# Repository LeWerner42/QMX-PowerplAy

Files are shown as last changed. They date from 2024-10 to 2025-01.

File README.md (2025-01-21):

# USB-C PD adapter for QMX + 50W PA

The QMX-PowerplAy is designed to power the [QRP Labs QMX](https://qrp-labs.com/qmx.html) as well as the [50W PA](https://qrp-labs.com/50wpa.html) off a USB PD Powerbank.
Designed for ultimate portability for SOTA / POTA activations, the board can negotiate `15V` or `20V` with `3A` or `5A` for the PA.
A `12V, 5A` switching regulator powers the QMX. Power Negotiation can be selected with simple Jumpers.

## Hardware
### Schematic
The main component is the [AP33771C](https://www.mouser.ch/ProductDetail/Diodes-Incorporated/AP33771CFBZ-13-FA01?qs=2wMNvWM5ZX7JpCFGcPz6nw%3D%3D) which takes care of USB PD negotiations.
Output Voltage and Current can be set through Jumpers `JP1` and `JP2`.
[The Barrel Jack](https://www.mouser.ch/ProductDetail/Wurth-Elektronik/694106301002?qs=a9WhcLg8qCwOEkcI62k5mA%3D%3D) J2 (5.5mm) directly connects to the negotiated power from USB.
J3 (5.5mm) is connected to the stepped-down 12V for supplying the QMX
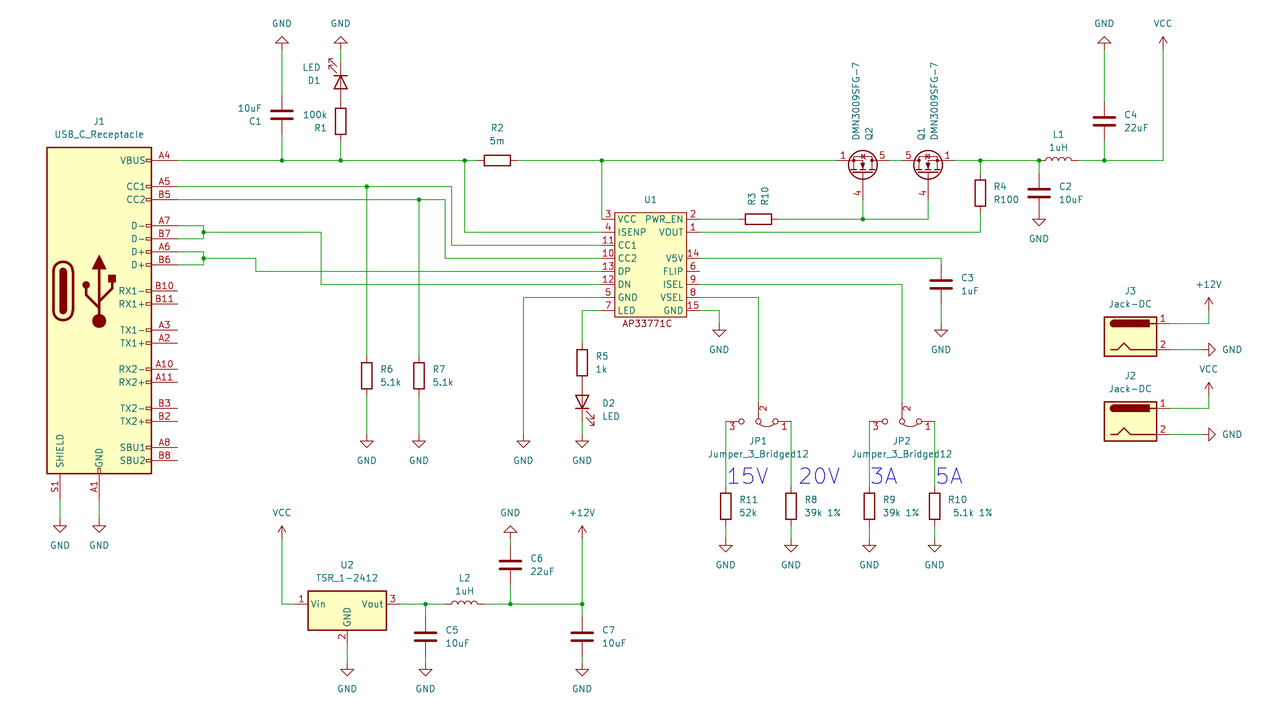
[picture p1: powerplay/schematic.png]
schematic Board Schematic


### Manufacturing
PCBs can be ordered with the gerbers in [fabrication](./powerplay/fabrication).  
The [Component BOM](https://lewerner42.github.io/QMX-PowerplAy/powerplay/bom/ibom.html) [`powerplay/bom/ibom.html`] lists all neccessary components for soldering.
Be aware of Capacitor Voltage ratings (>= 20V) for capacitors connected to USB power.
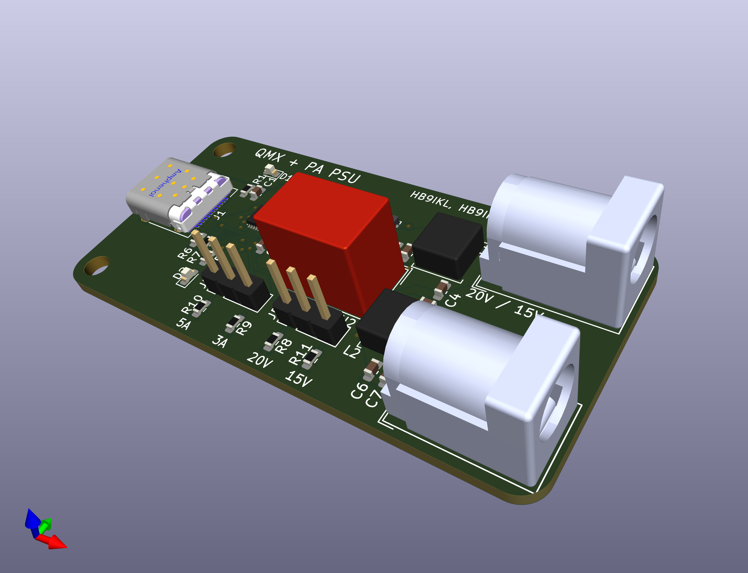
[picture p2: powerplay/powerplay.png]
rendering Board Render


## Case
The case is entirely 3D printable and files can be accessed in the [Case](./Case) folder.
The `12V` output is labled `QMX` and the USB power (`15V` or `20V`) is labled `PA`.

## Usage
No Substantial Load should be attached to the barrel jacks when powering up.
The QMX and PA can be connected during power-up.
Successfull power negotiation is indicated by LED 2 (`D2`) breathing.
LED 1 (`D1`) indicates if power is present at all.
In case of failiure to negotiate the requested power level either the highest possible negotiated power is present (e.g. `20V`, `3A` even though `100W` were requested) or only `5V` are present on the PA port.
The step-down (`12V` output) only works if the USB voltage is `> 12V`.
Jumpers `JP1` and `JP2` can be used to change the negotiated power according to the capabilities of the used supply.
The Power select Jumpers are NOT hot-swappable. Change them only when the device is unconnected.

# Authors
This board has been developed specifically for SOTA and POTA purposes by Pol (HB9IKL) and Lennart (HB9IKK).

# License


This work is licensed under Creative Commons Attribution-ShareAlike 3.0 Unported License. 
(http://creativecommons.org/licenses/by-sa/3.0/)

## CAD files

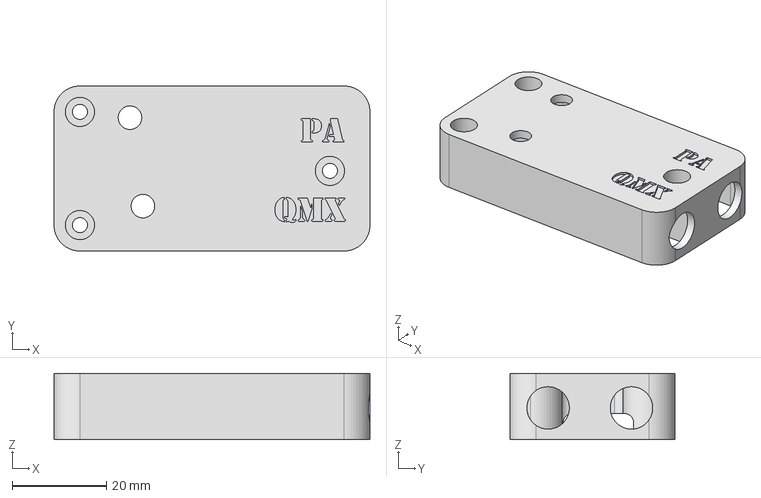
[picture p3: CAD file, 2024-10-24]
Case/Case_Cap.stp
67.0 x 35.0 x 14.0 mm

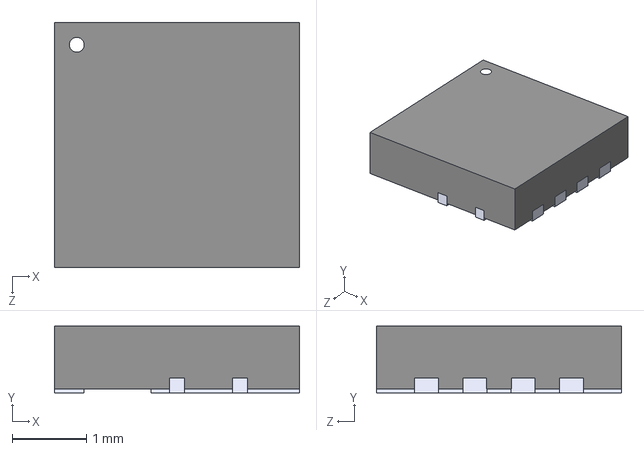
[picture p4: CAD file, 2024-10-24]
powerplay/3dModels/DMN3009SFG-7.stp
3.30 x 0.9 x 3.30 mm

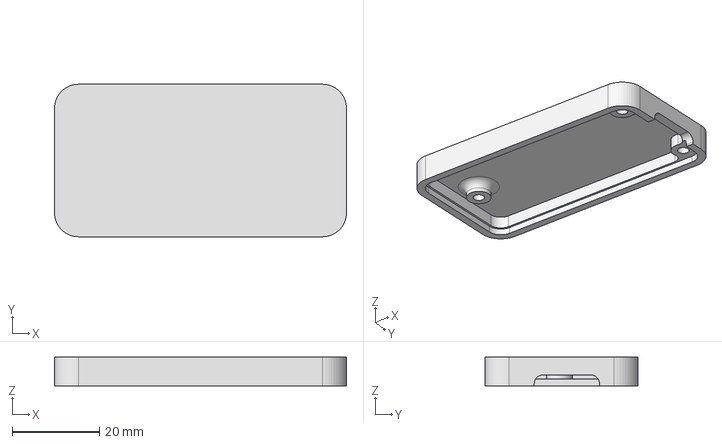
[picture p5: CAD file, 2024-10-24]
Case/case_base.stp
67.0 x 35.0 x 6.60 mm

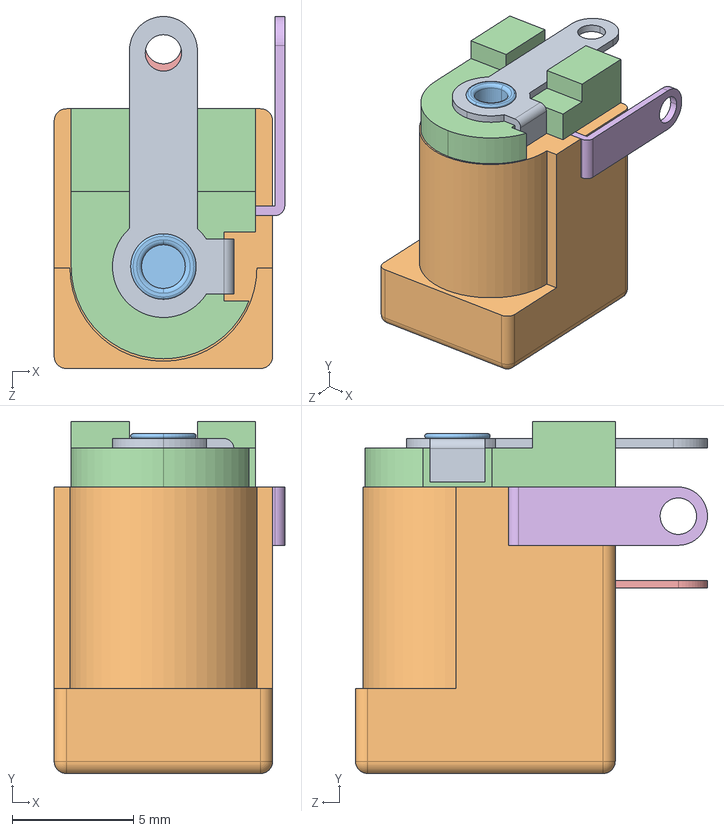
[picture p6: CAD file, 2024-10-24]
powerplay/3dModels/694106301002.stp
9.50 x 14.5 x 14.5 mm

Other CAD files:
Case/Case_Cap.ipt
Case/OldVersions/Case_Cap.0005.ipt
Case/OldVersions/case_assambly.0003.iam
Case/OldVersions/case_base.0003.ipt
Case/case_assambly.iam
Case/case_base.ipt

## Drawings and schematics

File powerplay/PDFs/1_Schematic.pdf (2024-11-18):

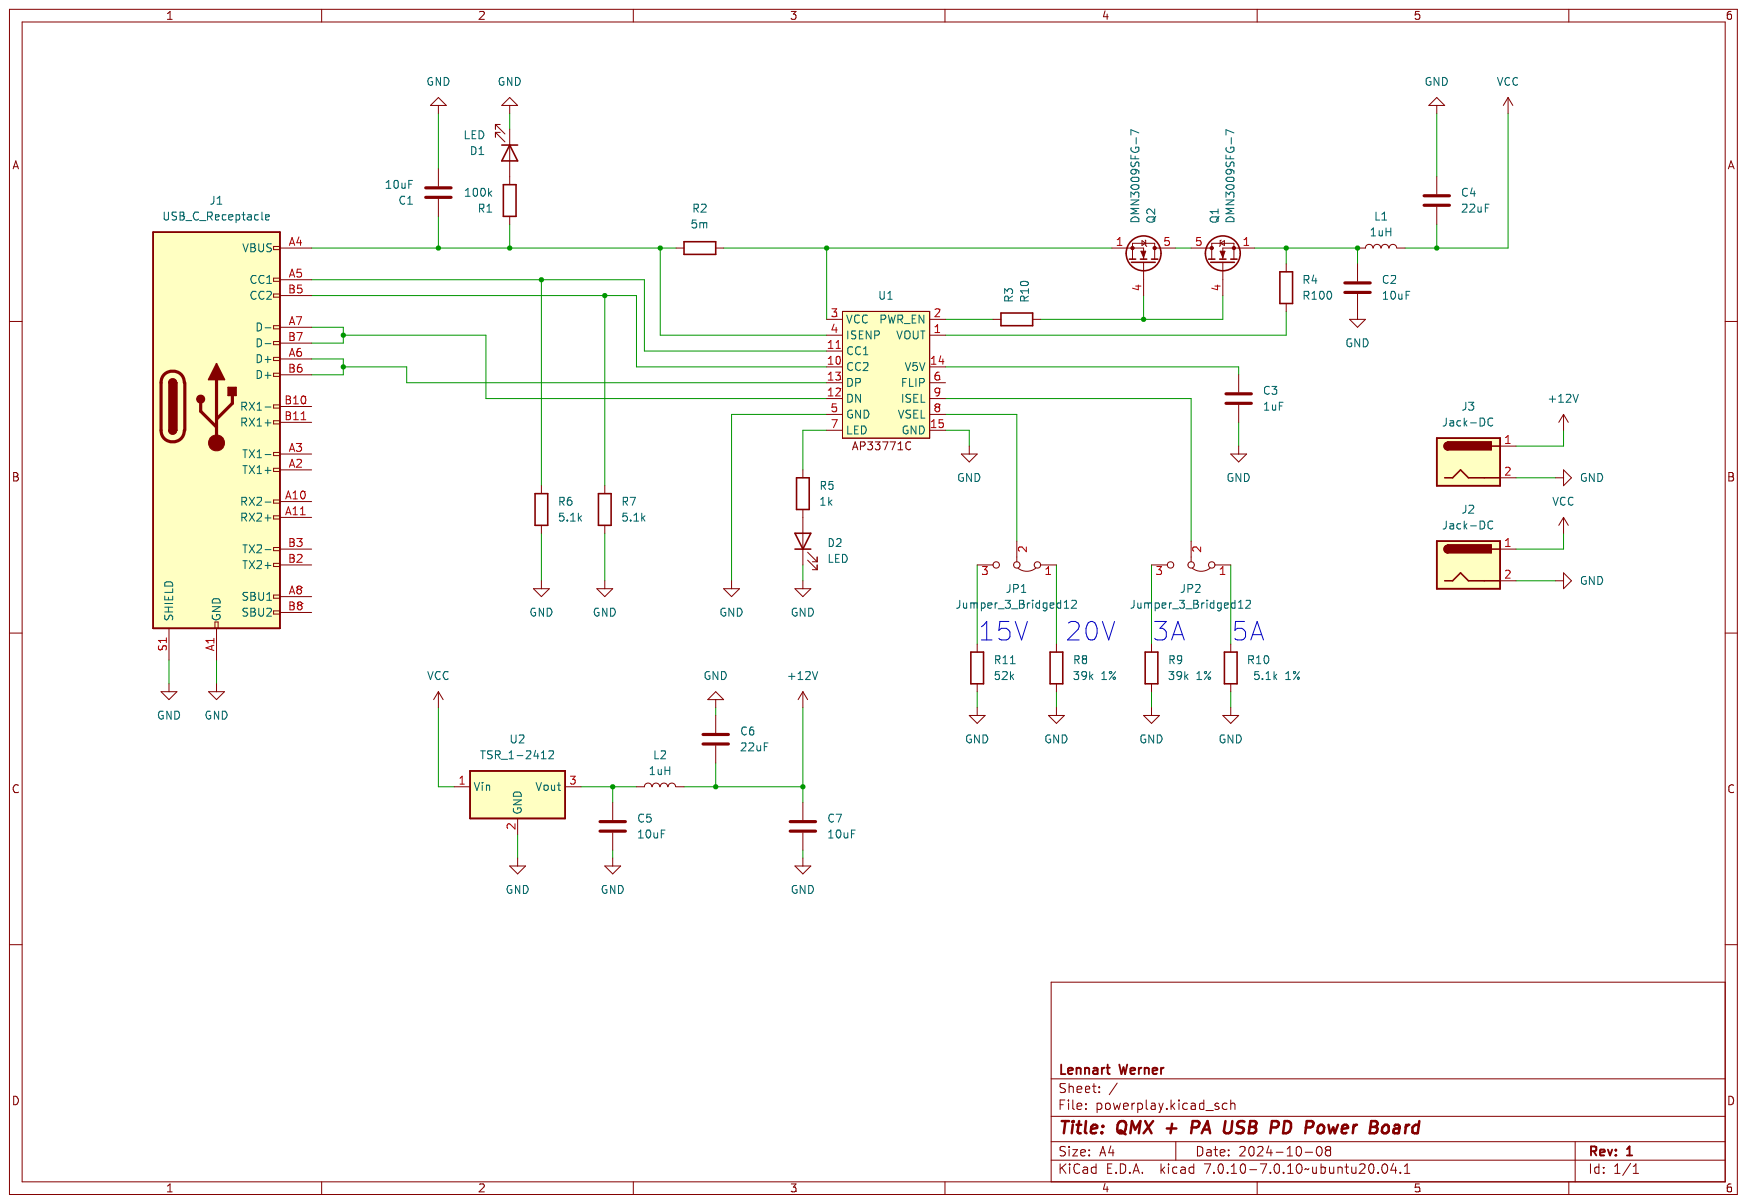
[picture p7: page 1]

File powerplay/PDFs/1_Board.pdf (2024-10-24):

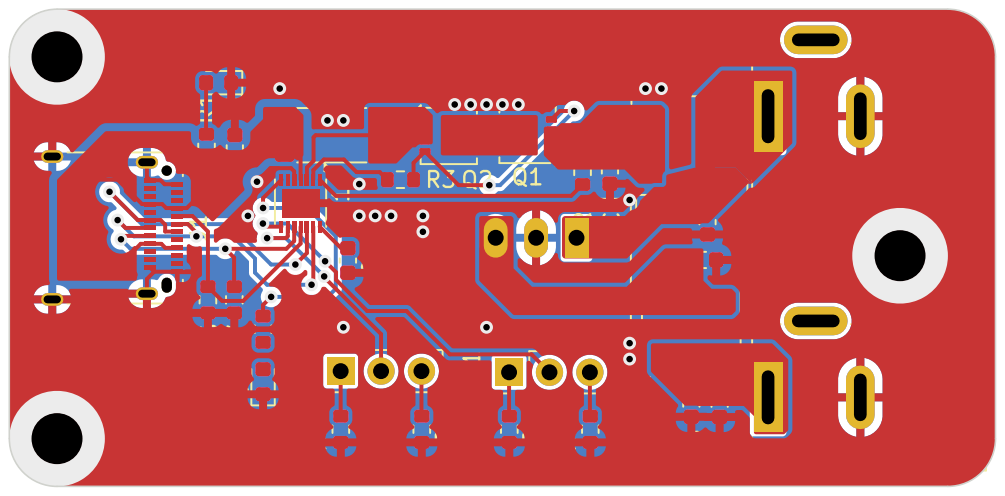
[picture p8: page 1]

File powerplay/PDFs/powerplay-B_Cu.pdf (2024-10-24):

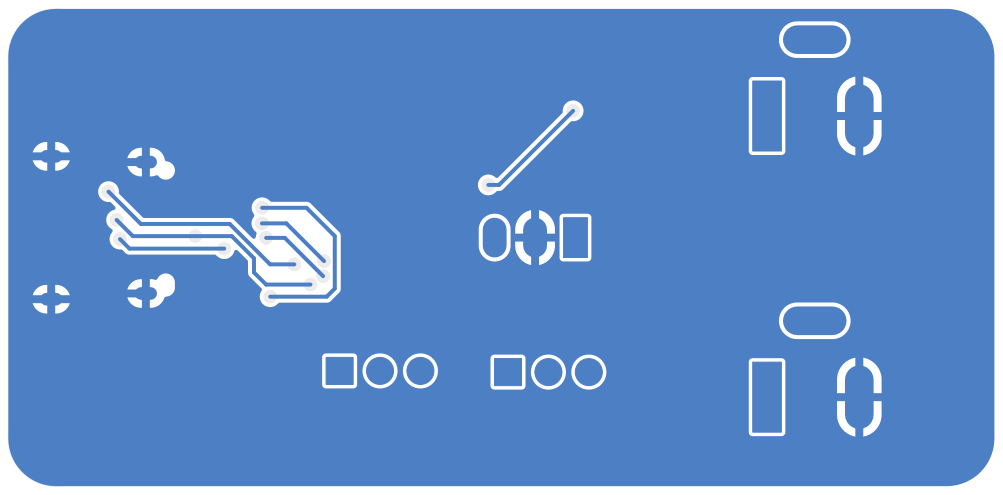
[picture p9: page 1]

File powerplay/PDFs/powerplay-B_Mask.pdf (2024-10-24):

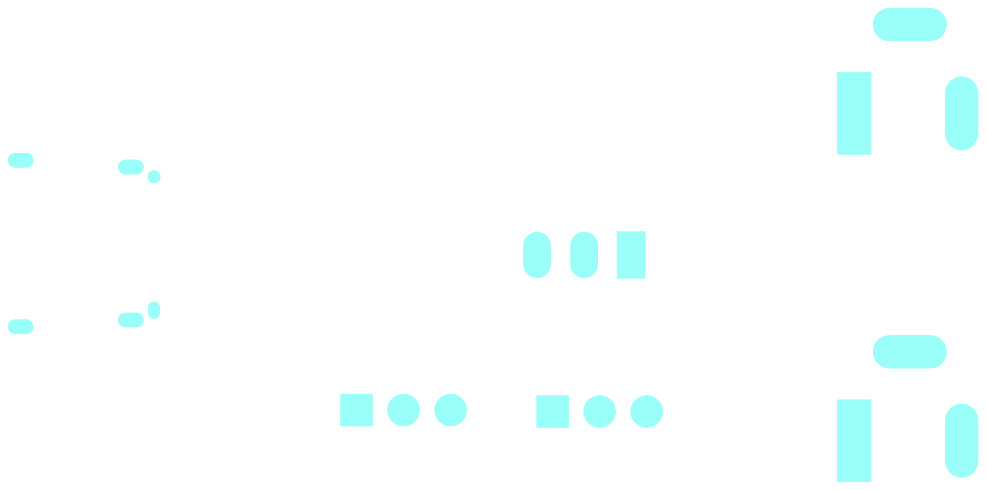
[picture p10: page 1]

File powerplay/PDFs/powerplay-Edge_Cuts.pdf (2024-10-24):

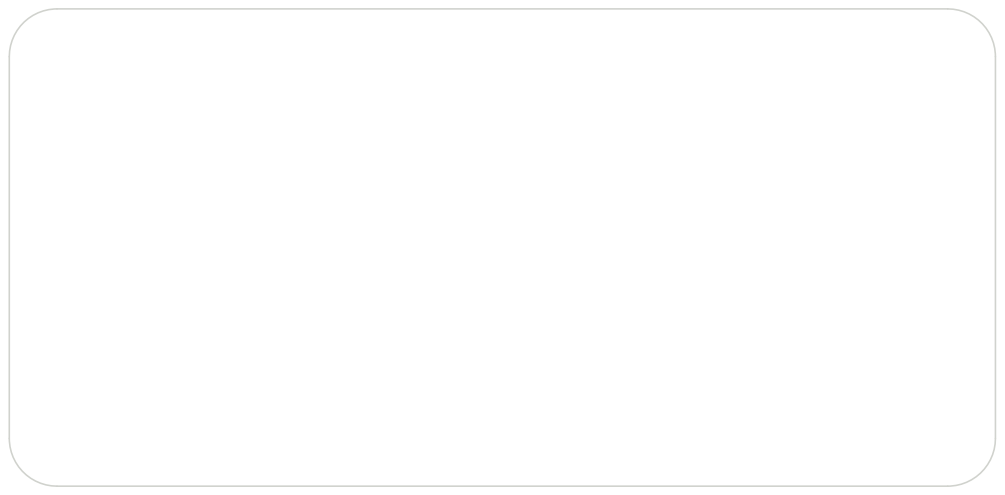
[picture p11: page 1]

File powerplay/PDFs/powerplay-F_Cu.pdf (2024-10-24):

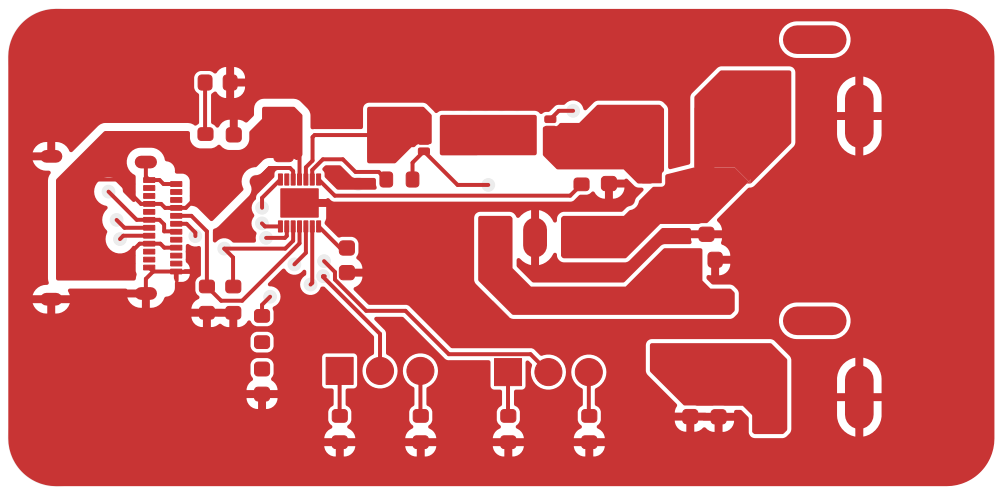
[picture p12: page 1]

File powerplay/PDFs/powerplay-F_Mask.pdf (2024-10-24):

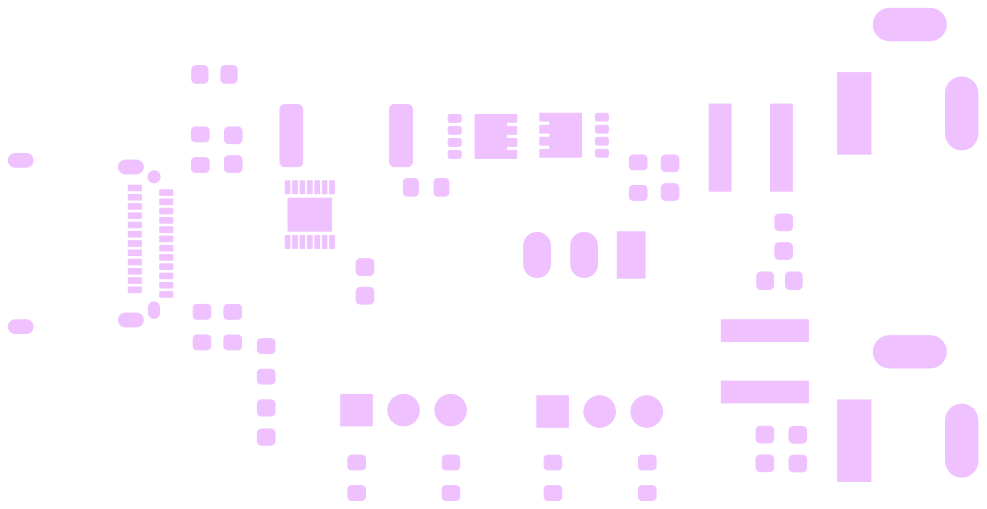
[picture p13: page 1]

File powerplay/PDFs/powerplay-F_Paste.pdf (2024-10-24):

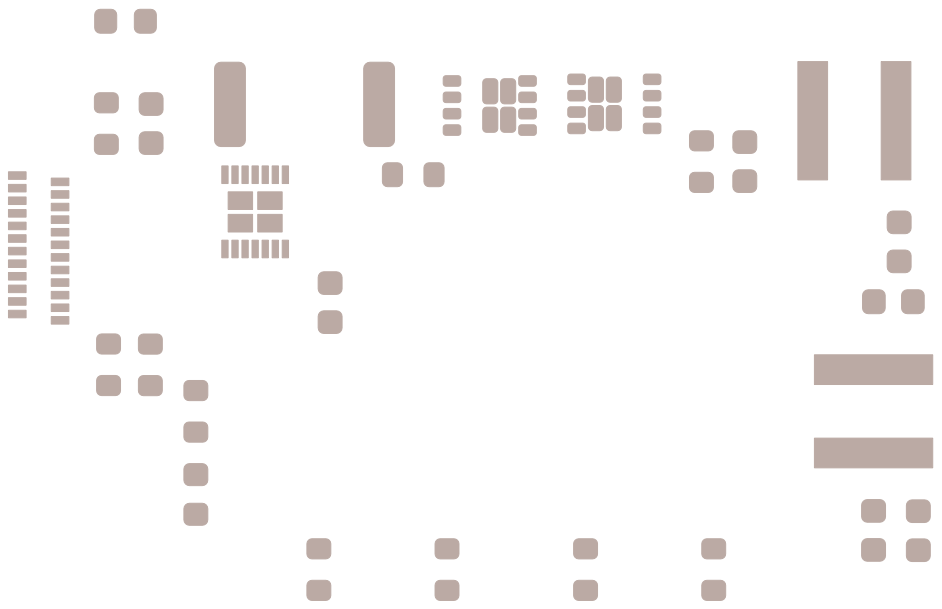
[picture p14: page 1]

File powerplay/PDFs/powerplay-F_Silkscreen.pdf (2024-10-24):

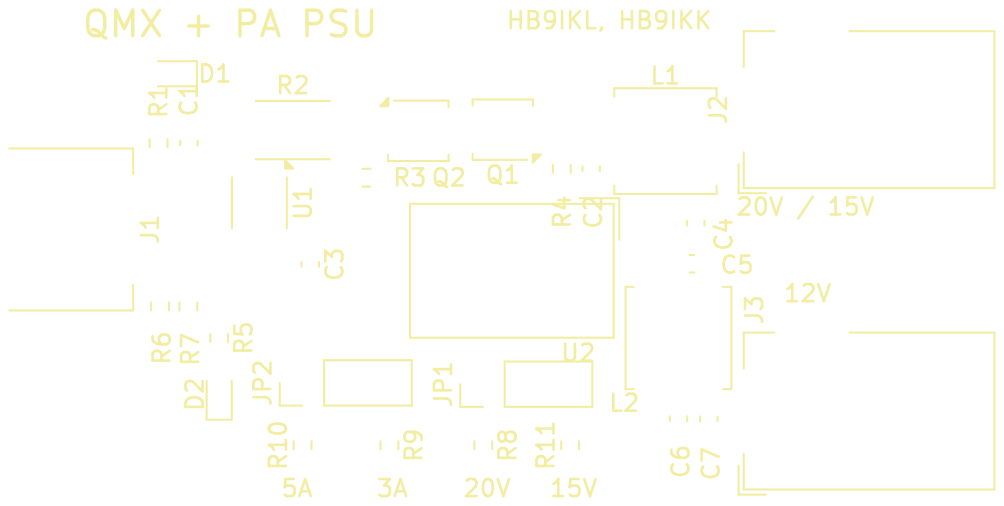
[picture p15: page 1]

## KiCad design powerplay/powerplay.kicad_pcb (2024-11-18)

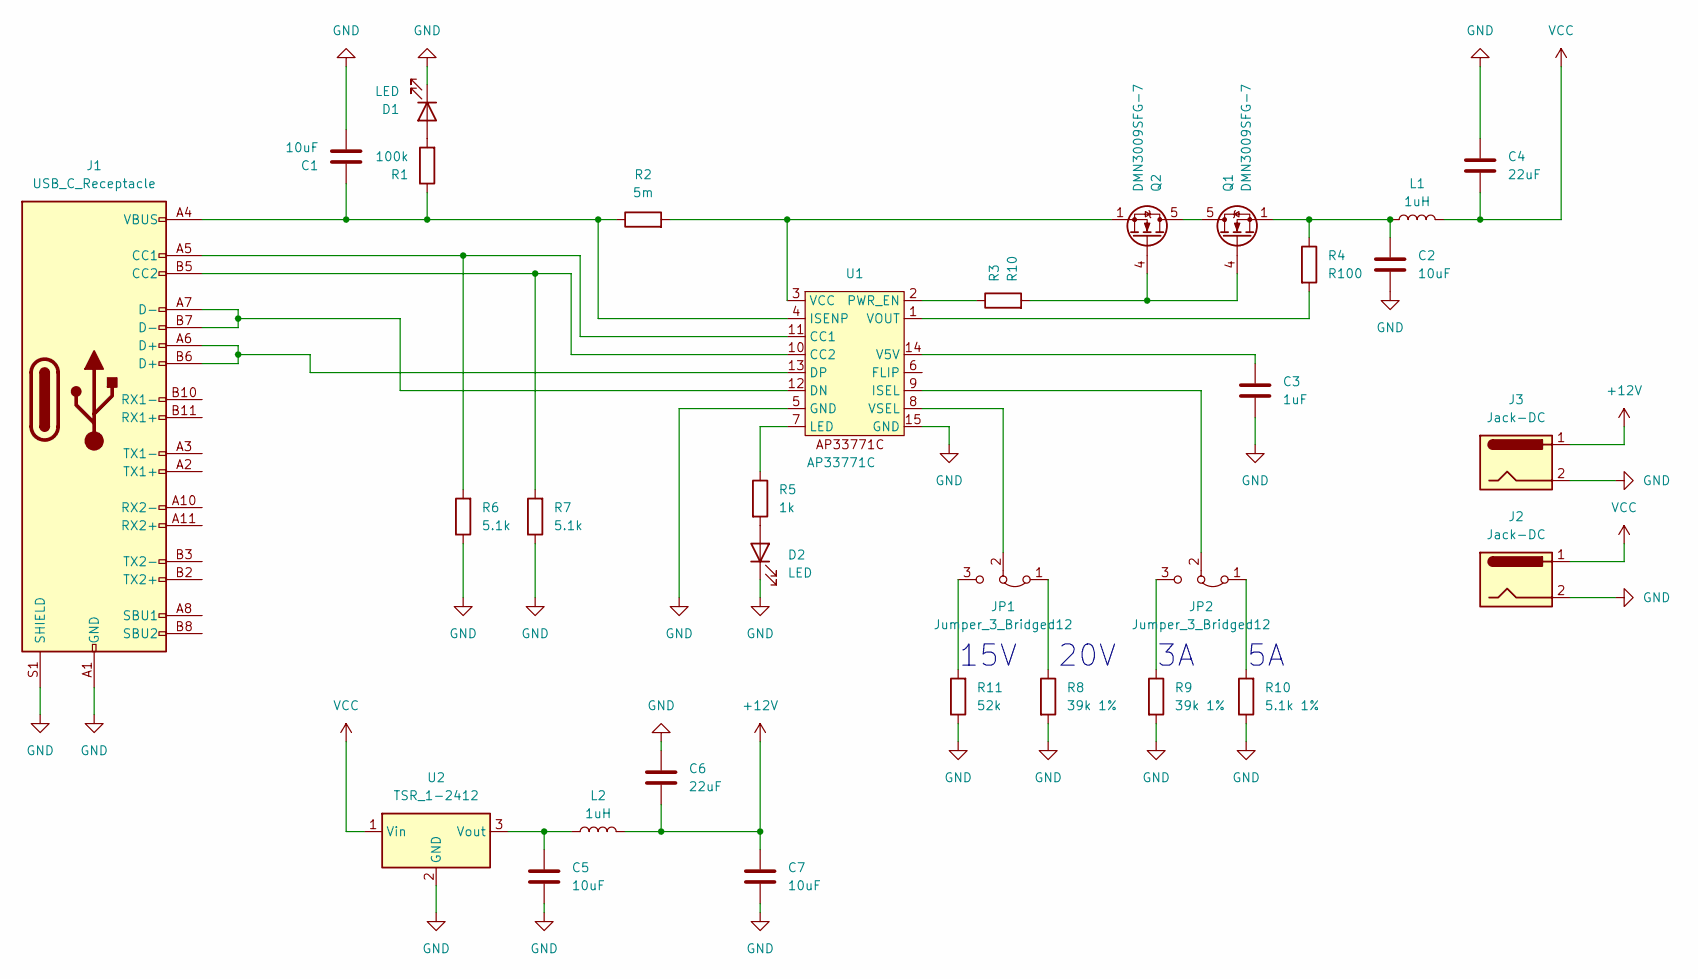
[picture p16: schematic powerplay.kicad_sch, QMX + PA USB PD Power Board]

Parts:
C1, C2, C5, C7: 10uF; C_0603_1608Metric
C3: 1uF; C_0603_1608Metric
C4, C6: 22uF; C_0603_1608Metric
D1, D2: LED; LED_0603_1608Metric
J1: USB_C_Receptacle; USB_C_Receptacle_Amphenol_12401610E4-2A
J2, J3: Jack-DC; BarrelJack_Wuerth_6941xx301002
JP1, JP2: Jumper_3_Bridged12; PinHeader_1x03_P2.54mm_Vertical
L1, L2: 1uH; L_Coilcraft_XAL5030-XXX
Q1, Q2: DMN3009SFG-7; Diodes_PowerDI3333-8
R1: 100k; R_0603_1608Metric
R2: 5m; R_2512_6332Metric
R3: R10; R_0603_1608Metric
R4: R100; R_0603_1608Metric
R5: 1k; R_0603_1608Metric
R6, R7: 5.1k; R_0603_1608Metric
R8, R9: 39k 1%; R_0603_1608Metric
R10: 5.1k 1%; R_0603_1608Metric
R11: 52k; R_0603_1608Metric
U1: AP33771C; DFN-14-1EP_3x3mm_P0.4mm_EP1.78x2.35mm
U2: TSR_1-2412; Converter_DCDC_TRACO_TSR-1_THT

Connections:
+12V: C6.2, C7.1, J3.1, L2.2
GND: C1.2, C2.2, C3.2, C4.1, C5.2, C6.1, C7.2, D1.1 (K), D2.1 (K), J1.A1 (GND), J1.A12 (GND), J1.B1 (GND), J1.B12 (GND), J1.S1 (SHIELD), J2.2, J3.2, R6.1, R7.1, R8.2, R9.2, R10.1, R11.1, U1.5 (GND), U1.15 (GND), U2.2 (GND)
unnamed: C2.1, L1.1, Q1.1 (S), Q1.2 (S), Q1.3 (S), R4.1
unnamed: D1.2 (A), R1.2
unnamed: D2.2 (A), R5.2
unnamed: J1.A5 (CC1), R6.2, U1.11 (CC1)
unnamed: J1.B5 (CC2), R7.2, U1.10 (CC2)
unnamed: JP1.1 (A), R8.1
unnamed: JP1.3 (B), R11.2
unnamed: JP1.2 (C), U1.8 (VSEL)
unnamed: JP2.1 (A), R10.2
unnamed: JP2.3 (B), R9.1
unnamed: JP2.2 (C), U1.9 (ISEL)
unnamed: Q1.5 (D), Q2.5 (D)
unnamed: Q1.4 (G), Q2.4 (G), R3.2
unnamed: J1.A7 (D-), J1.B7 (D-), U1.12 (DN)
unnamed: J1.A6 (D+), J1.B6 (D+), U1.13 (DP)
unnamed: C1.1, J1.A4 (VBUS), J1.A9 (VBUS), J1.B4 (VBUS), J1.B9 (VBUS), R1.1, R2.1, U1.4 (ISENP)
unnamed: R5.1, U1.7 (LED)
unnamed: R3.1, U1.2 (PWR_EN)
unnamed: C3.1, U1.14 (V5V)
unnamed: Q2.1 (S), Q2.2 (S), Q2.3 (S), R2.2, U1.3 (VCC)
unnamed: R4.2, U1.1 (VOUT)
unnamed: C5.1, L2.1, U2.3 (Vout)
VCC: C4.2, J2.1, L1.2, U2.1 (Vin)

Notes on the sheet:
20V
15V

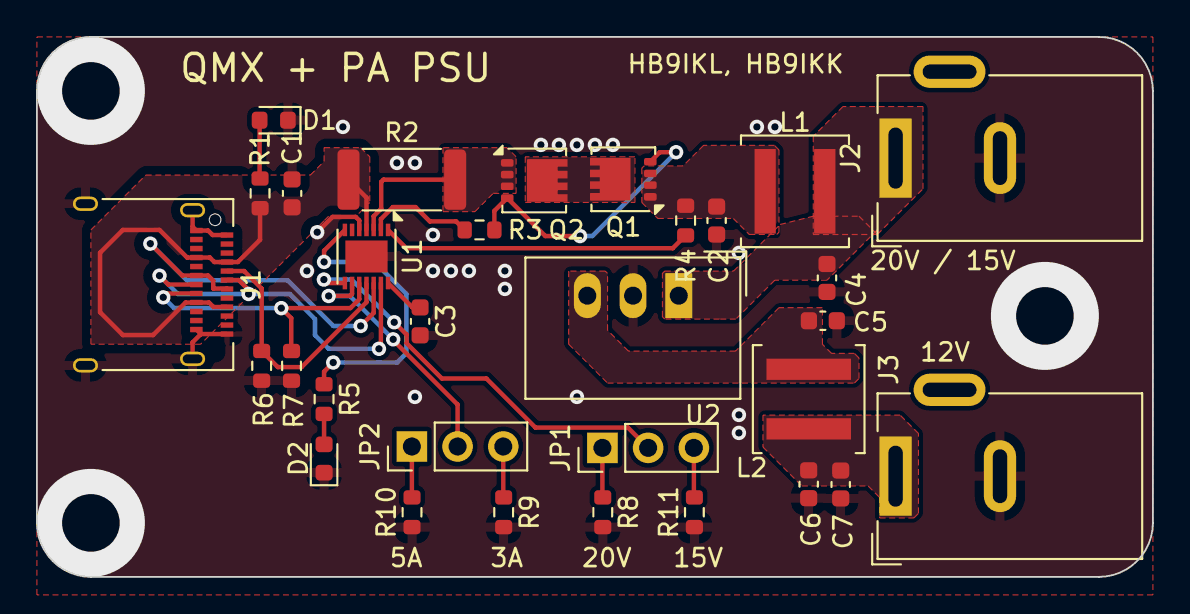
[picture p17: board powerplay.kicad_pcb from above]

Board: 2 copper layers, 62.0 x 30.0 mm, 31 parts (0 on the bottom side), 25 nets.
